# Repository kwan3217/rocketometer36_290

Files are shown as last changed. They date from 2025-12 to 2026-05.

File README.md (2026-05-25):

Moved to [GitHub](https://gitlab.com/kwan32171/rocketometer36_290)

This documents the data produced by the Rocketometer during NASA Sounding Rocket Flight 36.290, 2013 Oct 21.

# Encoding format
The data was captured and encoded in the form of CCSDS packets. The exact structure of each packet is most completely documented in the source code.

# Source code
The Rocketometer contains an LPC2148 ARM-based MCU with 512kiB flash memory. As this was far more memory than I needed for the firmware, I worked out a way to attach the source code of the firmware as well as the hardware design to the firmware itself. The Rocketometer spits this out into the packet stream as one of the first things it does at startup. How's that for configuration control?

The source code package is in the form of a ZPAQ TAR archive. The folder includes all the C++ source code, Makefiles, and such for rebuilding the firmware, which will be identical to the firmware carried on the flight with the exception of the date stamp on the firmware.

The hardware design is in the form of an Eagle CAD board and schematic, editable with the Eagle freeware version (as that is what it was designed with). It also includes a bill of materials in the form of Digikey catalog numbers for all parts used on the board.

The source code package is attached to the firmware, along with pointers to exactly where in the firmware the package begins and ends. This enables the firmware to copy a piece of itself into the packet stream as multiple CCSDS packets.

# Time Stamp
The firmware uses one of the MCU counter/timers for timing. This counter is a 32-bit unsigned number which starts at zero during firmware bootup, and counts up to one less than 3.6 billion counts exactly, at which point it resets to zero. The counter nominally runs at 60MHz, so this counter resets once every 60 seconds. Each time-sensitive packet (almost all of them except for some startup packets) have this count in it, and the packets are generated at such a rate that it is possible to unambiguously unwind the counter and get an exact number of counts since startup. Unfortunately the time of startup was not marked in any absolute time scale such as UTC, so absolute timing has to be inferred from timestamped events in the data.

# Sensor data
The sensor data stream consists of three separate streams of packets:
1. The Fast packet includes the MPU6050 3-axis acceleration, 3-axis rotation, and temperature readings, along with the ADXL377 3-axis high-acceleration readings. These were read once every 3 milliseconds and timestamped as indicated above.
2. The Compass packet includes the HMC5883 3-axis magnetic readouts. These were measured at a multiple of the Fast packet period (see the source code for details)
3. The BMP packet includes the BMP180 pressure and temperature readouts, both raw and calibrated into physical units.
4. The Power packet stream includes one packet each time the external power state changed (including one at startup).
5. The Vertical packet stream includes data on the vertical sensing fast/slow packet rate (see the source code for details). I have verified that this worked as intended, and that the entire flight was recorded at the fast rate.

# Packet storage
Packet storage was on a 16GB microSD card. Less than 1GB was used between the time I delivered the Rocketometer and the time it was returned to me.

# Power
The board consumes something around 100mA, not counting charging. The charger can use and additional 100mA. The system has an internal battery in the form of a 100mAh LiPo cell. The Rocketometer is powered externally by a 5V line from the rocket payload. It charges the battery with its on-board LiPo charging circuit as necessary when external power is available, and runs off the battery when external power is off. The on-board switch is not accessible, so the board is on whenever the rest of the rocket payload is on, and only turns off once its battery discharges. The battery is made safe by its standard integrated safety circuit and the dedicated LiPo charging circuit.

# The Flight
The Rocketometer was integrated with the rest of the rocket payload months before the flight. After that time, no human interaction whatsoever took place. It was returned to me for readout a couple of hours after the flight was completed. In that time, it recorded 65 files, one for each time it was power-cycled. The one containing the flight was file RKTO0620.SDS . This file contains 54.4 MB of data covering well over an hour, from about 35 minutes before the flight until well after impact. External power was cut 585 seconds after launch, and the on-board battery sustained it for the rest of the flight.

# Rail data
The file RKTO0620.SDS starts after the rail was raised to almost vertical. Other records were taken when the rail was horizontal, in particular RKTO0600.SDS. This data has been processed into the same tables and published. Interesting things such as orientation of the Rocketometer relative to the rail can be determined from that.

It would have been nice for the Rocketometer to have been recording while the rail was raised from horizontal to vertical. Unfortunately this did not happen. Maybe next time...

For whatever reason, it seems that no magnetic data was recorded while the rail was horizontal. Apparently magnetic data is not recorded when the board is recording at low rate.

# Rocketometer coordinate system
All sensors were co-aligned, so each individual sensor matches the whole Rocketometer frame. The Rocketometer was mounted close to the spin axis of the rocket, with the +Z axis pointed towards the tail. Consequently the thrust acceleration was primarily read out as a -Z acceleration. It should be parallel to that axis to within normal mechanical tolerances, almost certainly quite a bit better than 1°.

Based on the rail data, the +X axis of the Rocketometer was pointed almost straight down when the rocket was hanging horizontally from the rail.

In the flight after burnout but before spindown, the rocket was coasting well above the atmosphere and spinning with constant angular momentum, nearly around its long axis. Therefore the entire sensed acceleration is pure centripetal. Therefore, the distance and direction from the accelerometer to the spin axis can be measured. I did this once, but I wasn't sure about the signs and therefore didn't record it.

# Processing into tables
The packet stream format is not convenient or quick for import into IDL. For this purpose, a packet dumper, extractFast, was written in pure C which reads a Rocketometer data file, parses out each kind of packet, and writes each different apid into a different file. All the fast packets are together, all the slow packets, all the compass, all the source code, etc are each in their own file. Since the most common case is that each apid has a consistent length, this apid file can be read quickly into IDL by a read_binary, treating it as a 2D array of 16-bit integers, where rows are individual packets, and columns are fields in the packet.

Each packet is assigned a global sequence number, and this number is one of the things written to the APID file. With this sequence number, the order of different packets in different files can be determined.

These APID files are then imported into IDL, where the timestamps are normalized, values are converted in endian-ness as needed, and in general the packets are parsed. As this is an array operation, it can be done several orders of magnitude faster than parsing each packet individually in IDL.

The published tables have the timestamp normalized (cycle ambiguity fixed, converted into seconds, offset from power-on to launch subtracted) but otherwise the data is as recorded by the Rocketometer in flight. In particular, no translation from raw DNs to physical units is performed.

# Included files
* `RKTO0620.SDS.zip` - raw flight data file, PKZIP compressed
* `RKTO0600.SDS.zip` - raw rail data file, PKZIP compressed
* `firmware.tar.gz` - Firmware package, as flown (from RKTO0620.SDS) but zpaq uncompressed and gzip recompressed
* `extractFast.c` - C program described above
* `apid list.ods` - Some documentation of the packet format, not know to be completely up-to-date. Use the source code as the final authority.
* `import_fast.pro` - IDL program which converts extractFast output to CSV tables, among other things.
* `RKTO0620_csv.zip` - Compressed archive containing the following files
   * `RKTO0620_fast.csv` - Comma separated values, fast packets as described above
   * `RKTO0620_bmp.csv` - Comma separated values, BMP180 temperature and pressure readings, raw and calibrated into physical units by the Rocketometer in-flight
   * `RKTO0620_hmc.csv` - Comma separated values, HMC5883 magnetic readings, as described above.
* `RKTO0600_csv.zip` - Compressed archive containing the following files
   * `RKTO0600_fast.csv` - Comma separated values, fast packets as described above
   * `RKTO0600_bmp.csv` - Comma separated values, BMP180 temperature and pressure readings, raw and calibrated into physical units by the Rocketometer on-board

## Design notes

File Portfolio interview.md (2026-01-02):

1. Origin story -- What sparked this project 12+ years ago? Were you frustrated with 
  off-the-shelf loggers? Did a sounding rocket team need something better? Personal
  challenge?

The rollercoasterometer was inspired by Space Mountain. Most other roller coasters are
able to be seen. Space Mountain is unique for being in the dark. I wanted something to
trace the tracks. Other roller coasters could in principle use GPS, but Space Mountain,
being indoors, can't. I designed and implemented a fiber optic strain gauge accelerometer
for my senior project (2000-2001), thinking that something like that could be smuggled on
board in a back pack. This was about the time that MEMS sensors were becoming available, 
but they were out of reach for my budget. Fast forward several years to 2009. At this 
point, MEMS sensors were in their "Moore's Law" phase -- smaller, cheaper, more accurate, 
more axes, etc etc etc. I designed a breadboard-based "rollercoasterometer" which used several
Sparkfun breakout boards for several IMU and magnetic sensors plus a GPS, combined with a 
Sparkfun Logomatic with custom firmware. At the time I was working with SDO/EVE which includes
a sounding rocket component (documented in another page of the portfolio) and brought the
rollercoasterometer with me during various business trips, including one to the Cape for the
final Comprehensive Performance Test. The PI for SDO/EVE, Tom Woods, saw it, was impressed, 
and suggested that I put it on his sounding rocket. During the Cape trip I took it to Disney
World during a down day and successfully measured several roller coasters. However, in its
form, it was too large and heavy to fly.

While programming the Logomatic, I discovered that it was a quite powerful microcontroller
in its own right. Many people learned microcontrollers from Arduino. I got, used, and learned
from Arduino as well, but my first processor was the Logomatic and its controller, the LPC2148.
I learned about all of its additional features that the standard firmware didn't use. The stock
firmware is only capable of recording either ADC measurements or UART text streams, but not
both. I needed both since my IMUs were analog and the UART was connected to the GPS.

So, the Rocketometer is the natural evolution of the Rollercoasterometer. It is 0.9x2.1", less than
an ounce with 100mAh battery, and contains the next generation (2011-2012) digital IMU sensors. The 
Rocketometer doesn't have a GPS because stock civilian GPS units aren't designed for the 
dynamics a model rocket (or sounding rocket) experiences, and furthermore the sounding rocket mission
was inside an aluminum shell with controlled RF emission. They wouldn't have let me fly a GPS,
and it wouldn't have worked. Even so, the Rocketometer has a UART and can receive GPS and PPS
data and record it. It works fine as a rollercoasterometer.

Note that nowadays most smartphones contain sensors as good as those in the rocketometer, and I use
them along with a custom app to do my "rollercoasterometry" these days. I turn on the app, put the
phone in my pocket, and record the ride. This just didn't exist yet in 2009-2013.

2. The big technical constraints you had to wrestle -- Size, weight, power budget? 
   Vibration/shock levels you designed for? Sampling rate goals vs. what was actually 
   achievable? Any “this will never work” moments you solved?

The biggest technical constraint is that the rocketometer had no telemetry and no control
from the time I handed it to Dr Woods for integration into the sounding rocket. It had to
work completely unattended for months. This drove some design decisions:

* Power -- The rocketometer receives power from the rest of the payload, in the form of a +5VDC
  line. But, the payload is explicitly powered down before sounding rocket reentry, meaining
  that I needed to supply my own power for at least 10 minutes. The rocketometer used its charging
  circuit to top up its 100mAh battery from the provided 5V, then seamlessly uses the rail and battery
  during a mission. Once supplied power drops, the device seamlessly transitions to using the battery
  which provided 30 additional minutes of recording time, plenty enough for reentry.
* Data volume -- At the time, 16GB microSD cards were the state of the art. Furthermore, the card
  and filesystem driver in the firmware used FAT32, limiting files to just under 4GiB. To handle this, 
  the data stream was broken into 2GiB chunks. Each power cycle of the device started a new series
  of recording files, and each file was a 2GiB chunk of packet data. I wasn't sure how long the device
  would be powered up before, during, or after the launch campaign, so I designed a low-rate mode
  where it only sampled 1/10 as fast. The device would check whether it was vertical by watching its
  own IMU reaction to gravity. Whenever it measured vertical, it automatically shifted to high rate
  for the next 30min. It checked verticality every second, so the 30min timer started when the 
  sounding rocket burned out. I had paid attention to the Genesis spacecraft which had a flaw in its
  IMUs, which were installed backwards, and as a consequence didn't pop its parachute. So I programmed
  the rocketometer to declare vertical if the rocket was either nose-up or nose-down. It was a good thing
  since it was installed inverted from how I thought and vertical was being read as nose down. The
  raw data didn't depend on this, and the verticality detector worked, so the part recorded the flight
  just fine
* Software reliability -- I ran the part for days, accumulating runtime. If the part ever crashed,
  I used the debugging tools I could to find the issue and fix it. As it turns out, there were no
  crashes.

3. Key design decisions you’re still proud of -- Why bare-metal instead of an RTOS? Specific IMU 
   choice and why? Power sequencing tricks? Mechanical mounting/isolation? Anything you did that
   was unusually clever for the era?
Bare metal was a design decision I inherited from the Logomatic. The Rocketometer was in a sense a
re-spin of the open-source Sparkfun Logomatic. I took its design, added the sensors based on the 
reference design in each sensor's datasheet, and integrated the whole thing on a much smaller board.
The firmware eventually contained not one byte of Sparkfun code (I even rewrote the linker script 
and Makefiles) but that was more ship-of-Theseus. Bare metal is still the right way to go on this
part, and I leveraged my experience with AIM/CIPS flight software for a realtime bare-metal executive.

The thing that would count as "unusually clever" was my firmware's documentation of itself. Long
ago I put a feature into the rollercoasterometer which could dump the microcontroller's flash memory.
My thought was that this way I can see the machine code and debug it that way. But I realized that
there is a better way. I added a feature to the Makefile to make an archive of the entire source code
and hardware design files, then attach the archive to the binary firmware. The linker script put the
archive into a section and pointed some symbols at it, and the firmware at runtime interpreted those
symbols as pointers and dumped the firmware archive as packets. This way each packet stream contains
the source code of the device that generated it.

4. The sounding rocket flight -- Which program/vehicle was it (NASA Sounding Rocket, university, 
commercial)? What was your role on the payload team? Apogee of 285.1424 km is insane — was that a
record or near-record for that vehicle class? Any tense moments during integration or launch?

The rocket was `NASA 36.290 UE WOODS/UNIV. OF COLORADO` . This is a Terrier-Black Brant IX, two stage
sounding rocket. We launched from White Sands launch complex 36 on 2013-10-21. I assisted with ground
integration -- there are always more hands needed and not enough time in a sounding rocket launch. I
learned our telemetry system and made sure the realtime display worked, and then on launch day I was
the space weather observer. We didn't want to launch during a solar flare, so I watched our in-space
SDO/EVE realtime data and made the call and hour, 30 min, and 1 min before launch that no solar flares
were in progress.

The flight was completely smooth, being the sixth that this team had conducted. The tensest moment
for the rocketometer was when I got it back, took the MicroSD card out of it, put it in my laptop, and
the laptop said "What card?" It took a few minuted before it recognized the card, but once it did,
I had 419MiB of data, including 54.4MiB of data from the flight (and 64 other power cycles). I was able
to verify the launch acceleration pulse and then knew I had good data.

5. Data highlights -- What’s the coolest thing the data revealed? Cleanest plot you ever pulled off 
the SD card? Did it catch something the principal experiment missed? Any post-flight “holy crap, 
look at that spike” moments?

The data showed a 12G first stage, -1.5G between stages, about 8G second stage, and spikes of up to
25G during reentry. That was the most surprising thing -- zero G at 2100m/s, through a 25G spike, 
down to 1G terminal velocity in under 25 seconds. The upper atmosphere is a wall -- that's what 
exponential decay (or growth coming back down) does for you. It surprises a lot of people that 
reentry is so harsh. The scientists and engineers knew about the reentry and designed for it, but 
it's still surprising that reentry is more "violent" than launch. The sensor I launched had a range
of +-16G, which I knew was close to what was expected during launch. I included a secondary +-250G 
sensor to catch data where the primary sensor saturated.

Also, the pressure sensor was rated from 0.3 to 1.3 bar, but did record 0 bar during the in-space
portion of the flight. It's just that the exact readings below 0.3 bar can't be trusted.

6. Failures or near-failures -- Be honest — any flights where it didn’t work perfectly? What broke,
and what did you change for the next one? SpaceX loves people who’ve debugged real hardware in the
field.

Alan Stern said about New Horizons at Pluto, that during the encounter, they don't want to learn
anything new about the spacecraft, only about Pluto. All of the bugs/"interesting features" are
to be known before encounter during rehearsals etc and fixed, worked around, or planned for.
I basically achieved that. The nose-down reading could have scuttled it, but the worst case
would have been recording the flight at 1/10 of design data rate, not "no data". By the time of the
sounding rocket, this exact device had flown in a model rocket, run for days on end, and was as
good as I could make it.

7. Longevity angle -- You said it’s 12 years old and still works — have you powered it up recently?
Flown it again? Still have the exact as-flown code running on the bench?

The flight was 12 years ago. The primary mission was for me to collect a piece of space-flown 
hardware as a "trophy". I still have it, mounted on a plaque for my mantel. It is only a trophy now.
I think that it still works, but the last time I fired it up was about 3 years ago, and I didn't
test the sensors, just the microcontroller.

8. Personal touches -- The embroidered patch — whose idea? Did you design it? Any other fun 
artifacts (stickers, T-shirts, war stories from the range)?

Every space mission needs a patch, and I designed one for this mission. It's pretty typical for
space mission patches. It has an oval shape with a picture of a 1950's sci-fi rocket with flames
coming out of it, connected to a voltmeter by two wires. The rocket represents the "rocket-" part
and the voltmeter represents the "-ometer" part. The rocket is high above the curved horizon of Earth.
In the background, there are 3 big and 2 small stars to the left of the rocket, and 1 big and
7 small stars to the right. This represents kwan3217. The border has the text "Rocketometer 36.290"
on the top of the oval, and "NASA - CU/LASP - SKHFTTADD" on the bottom where crew names (for manned flights)
or organization names (for unmanned flights) go. NASA and CU/LASP are obvious. SKHFTTADD is "St Kwan's Home
for the Terminally ADD", which is a pseudo-organization I made for myself.

I made several tab shirts with this patch embroidered into it, and also made some stickers which I stuck
on the tail fin of the first stage and on a window in the blockhouse next to stickers from all of their
other missions.

9. SpaceX hook -- When you imagine a Starship flight test engineer looking at this page, what do
you most want them to think? What part of Rocketometer feels closest to the instrumentation
challenges on Starship or Raptor test stands?

The biggest application to SpaceX is that I am a competent hardware and software designer, able
to integrate parts with "glue logic" like the custom PCB and microcontroller firmware, and that
I incorporate the NASA philosophy that I learned from the projects at LASP and conducted an 
experiment/built an instrument/implemented a project from beginning to end.

10. One-sentence elevator pitch -- If you had 10 seconds with Elon or a Starship avionics lead, how would you describe Rocketometer in one breath?

Custom microcontroller board with integrated IMU, battle-tested in space flight.

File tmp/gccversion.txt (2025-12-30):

Using built-in specs.
COLLECT_GCC=arm-none-eabi-gcc
COLLECT_LTO_WRAPPER=/usr/local/arm/libexec/gcc/arm-none-eabi/4.7.2/lto-wrapper
arm-none-eabi-gcc (GCC) 4.7.2
Copyright (C) 2012 Free Software Foundation, Inc.
This is free software; see the source for copying conditions.  There is NO
warranty; not even for MERCHANTABILITY or FITNESS FOR A PARTICULAR PURPOSE.

Target: arm-none-eabi
Configured with: ../gcc-4.7.2/configure --target=arm-none-eabi --prefix=/usr/local/arm --enable-interwork --enable-multilib --enable-languages=c,c++ --with-newlib --with-gnu-as --with-gnu-ld --disable-nls --disable-shared --disable-threads --with-headers=newlib/libc/include --disable-libssp --disable-libstdcxx-pch --disable-libmudflap --disable-libgomp --disable-werror --with-system-zlib --disable-newlib-supplied-syscalls
Thread model: single
gcc version 4.7.2 (GCC) 
COLLECT_GCC_OPTIONS='--version' '-v'
 /usr/local/arm/libexec/gcc/arm-none-eabi/4.7.2/cc1 -quiet -v -D__USES_INITFINI__ help-dummy -quiet -dumpbase help-dummy -auxbase help-dummy -version --version -o /tmp/ccWipwGV.s
GNU C (GCC) version 4.7.2 (arm-none-eabi)
	compiled by GNU C version 4.6.3, GMP version 4.3.2, MPFR version 2.4.2, MPC version 0.8.1
GGC heuristics: --param ggc-min-expand=100 --param ggc-min-heapsize=131072
COLLECT_GCC_OPTIONS='--version' '-v'
 /usr/local/arm/lib/gcc/arm-none-eabi/4.7.2/../../../../arm-none-eabi/bin/as -v -meabi=5 --version -o /tmp/ccyAZ0tG.o /tmp/ccWipwGV.s
GNU assembler version 2.22 (arm-none-eabi) using BFD version (GNU Binutils) 2.22
GNU assembler (GNU Binutils) 2.22
Copyright 2011 Free Software Foundation, Inc.
This program is free software; you may redistribute it under the terms of
the GNU General Public License version 3 or later.
This program has absolutely no warranty.
This assembler was configured for a target of `arm-none-eabi'.
COMPILER_PATH=/usr/local/arm/libexec/gcc/arm-none-eabi/4.7.2/:/usr/local/arm/libexec/gcc/arm-none-eabi/4.7.2/:/usr/local/arm/libexec/gcc/arm-none-eabi/:/usr/local/arm/lib/gcc/arm-none-eabi/4.7.2/:/usr/local/arm/lib/gcc/arm-none-eabi/:/usr/local/arm/lib/gcc/arm-none-eabi/4.7.2/../../../../arm-none-eabi/bin/
LIBRARY_PATH=/usr/local/arm/lib/gcc/arm-none-eabi/4.7.2/:/usr/local/arm/lib/gcc/arm-none-eabi/4.7.2/../../../../arm-none-eabi/lib/
COLLECT_GCC_OPTIONS='--version' '-v'
 /usr/local/arm/libexec/gcc/arm-none-eabi/4.7.2/collect2 -X --version /usr/local/arm/lib/gcc/arm-none-eabi/4.7.2/crti.o /usr/local/arm/lib/gcc/arm-none-eabi/4.7.2/crtbegin.o /usr/local/arm/lib/gcc/arm-none-eabi/4.7.2/../../../../arm-none-eabi/lib/crt0.o -L/usr/local/arm/lib/gcc/arm-none-eabi/4.7.2 -L/usr/local/arm/lib/gcc/arm-none-eabi/4.7.2/../../../../arm-none-eabi/lib /tmp/ccyAZ0tG.o --start-group -lgcc -lc --end-group /usr/local/arm/lib/gcc/arm-none-eabi/4.7.2/crtend.o /usr/local/arm/lib/gcc/arm-none-eabi/4.7.2/crtn.o
collect2 version 4.7.2
/usr/local/arm/lib/gcc/arm-none-eabi/4.7.2/../../../../arm-none-eabi/bin/ld -X --version /usr/local/arm/lib/gcc/arm-none-eabi/4.7.2/crti.o /usr/local/arm/lib/gcc/arm-none-eabi/4.7.2/crtbegin.o /usr/local/arm/lib/gcc/arm-none-eabi/4.7.2/../../../../arm-none-eabi/lib/crt0.o -L/usr/local/arm/lib/gcc/arm-none-eabi/4.7.2 -L/usr/local/arm/lib/gcc/arm-none-eabi/4.7.2/../../../../arm-none-eabi/lib /tmp/ccyAZ0tG.o --start-group -lgcc -lc --end-group /usr/local/arm/lib/gcc/arm-none-eabi/4.7.2/crtend.o /usr/local/arm/lib/gcc/arm-none-eabi/4.7.2/crtn.o
GNU ld (GNU Binutils) 2.22
Copyright 2011 Free Software Foundation, Inc.
This program is free software; you may redistribute it under the terms of
the GNU General Public License version 3 or (at your option) a later version.
This program has absolutely no warranty.

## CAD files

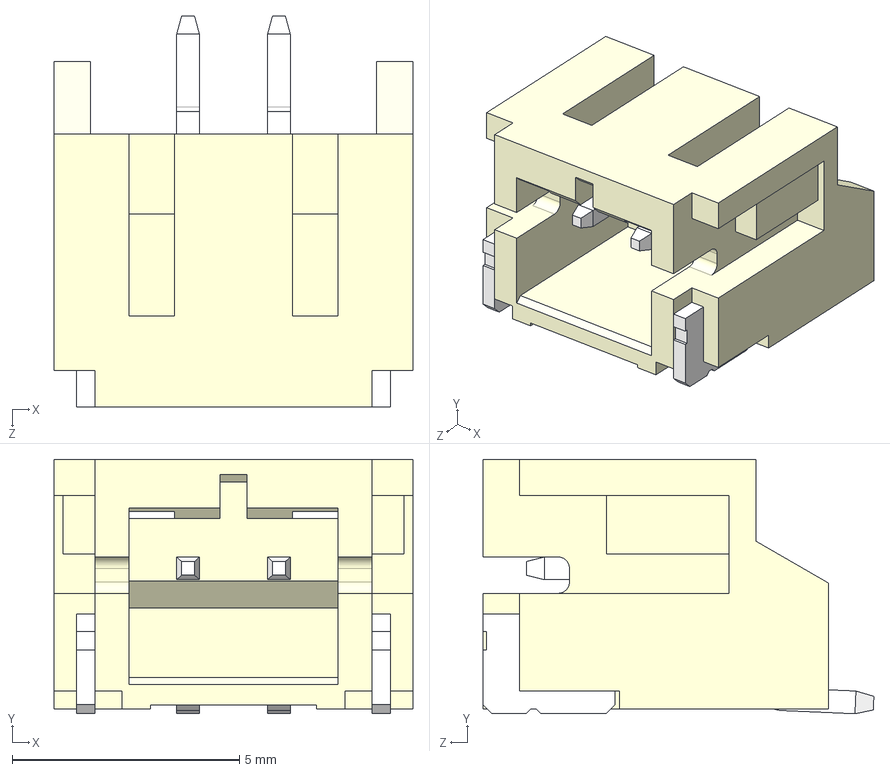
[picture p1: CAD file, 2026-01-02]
kicad/S2B-PH-SM4-TB.STEP
7.90 x 5.60 x 8.60 mm

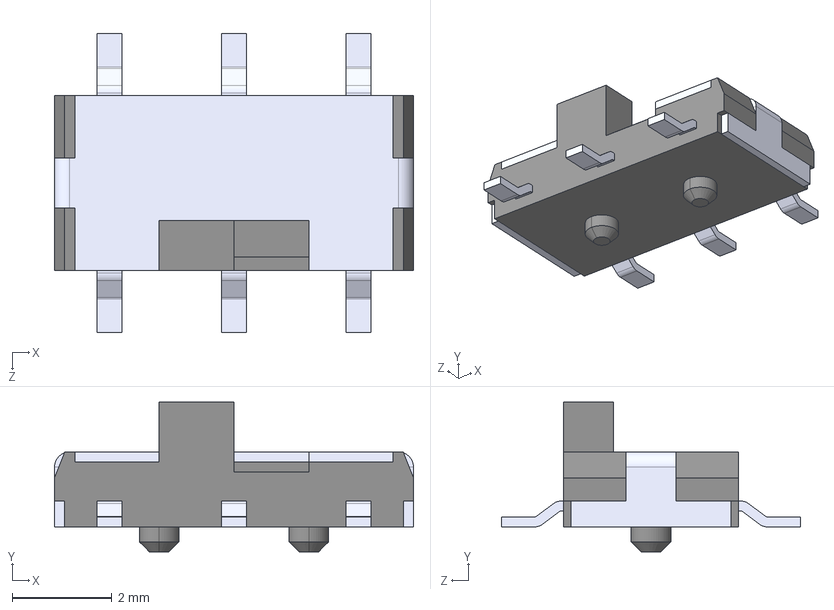
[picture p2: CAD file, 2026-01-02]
kicad/AYZ0202AGRLC.STEP
7.20 x 3.00 x 6.00 mm

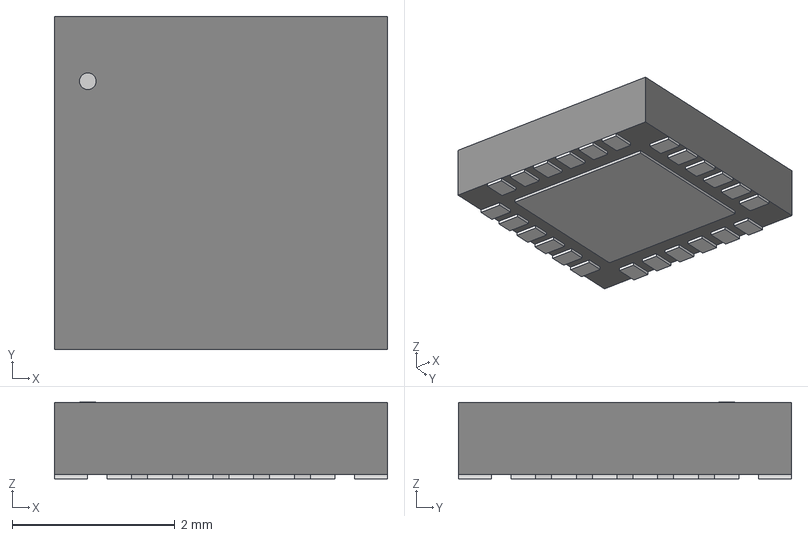
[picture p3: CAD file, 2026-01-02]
kicad/QFN24_4X4X0P9-0P5_TDK.step
4.09 x 4.09 x 0.942 mm

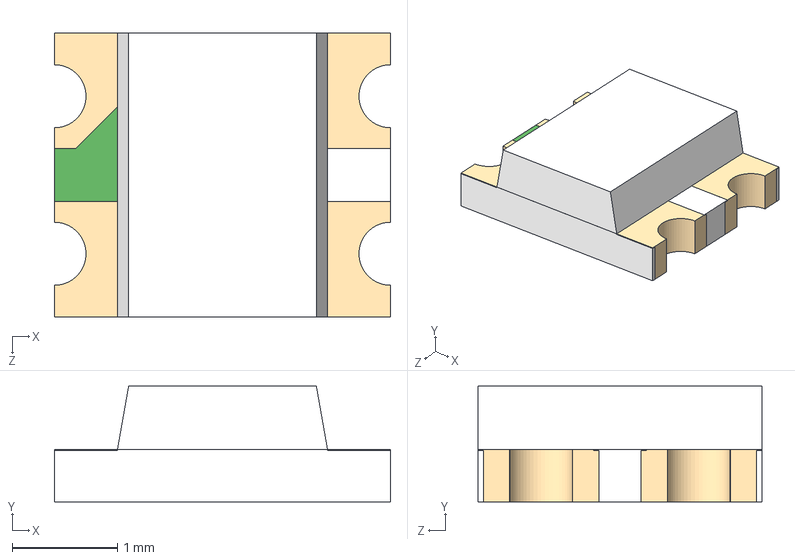
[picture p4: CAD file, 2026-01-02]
kicad/HSMF-C118.STEP
3.20 x 1.10 x 2.70 mm

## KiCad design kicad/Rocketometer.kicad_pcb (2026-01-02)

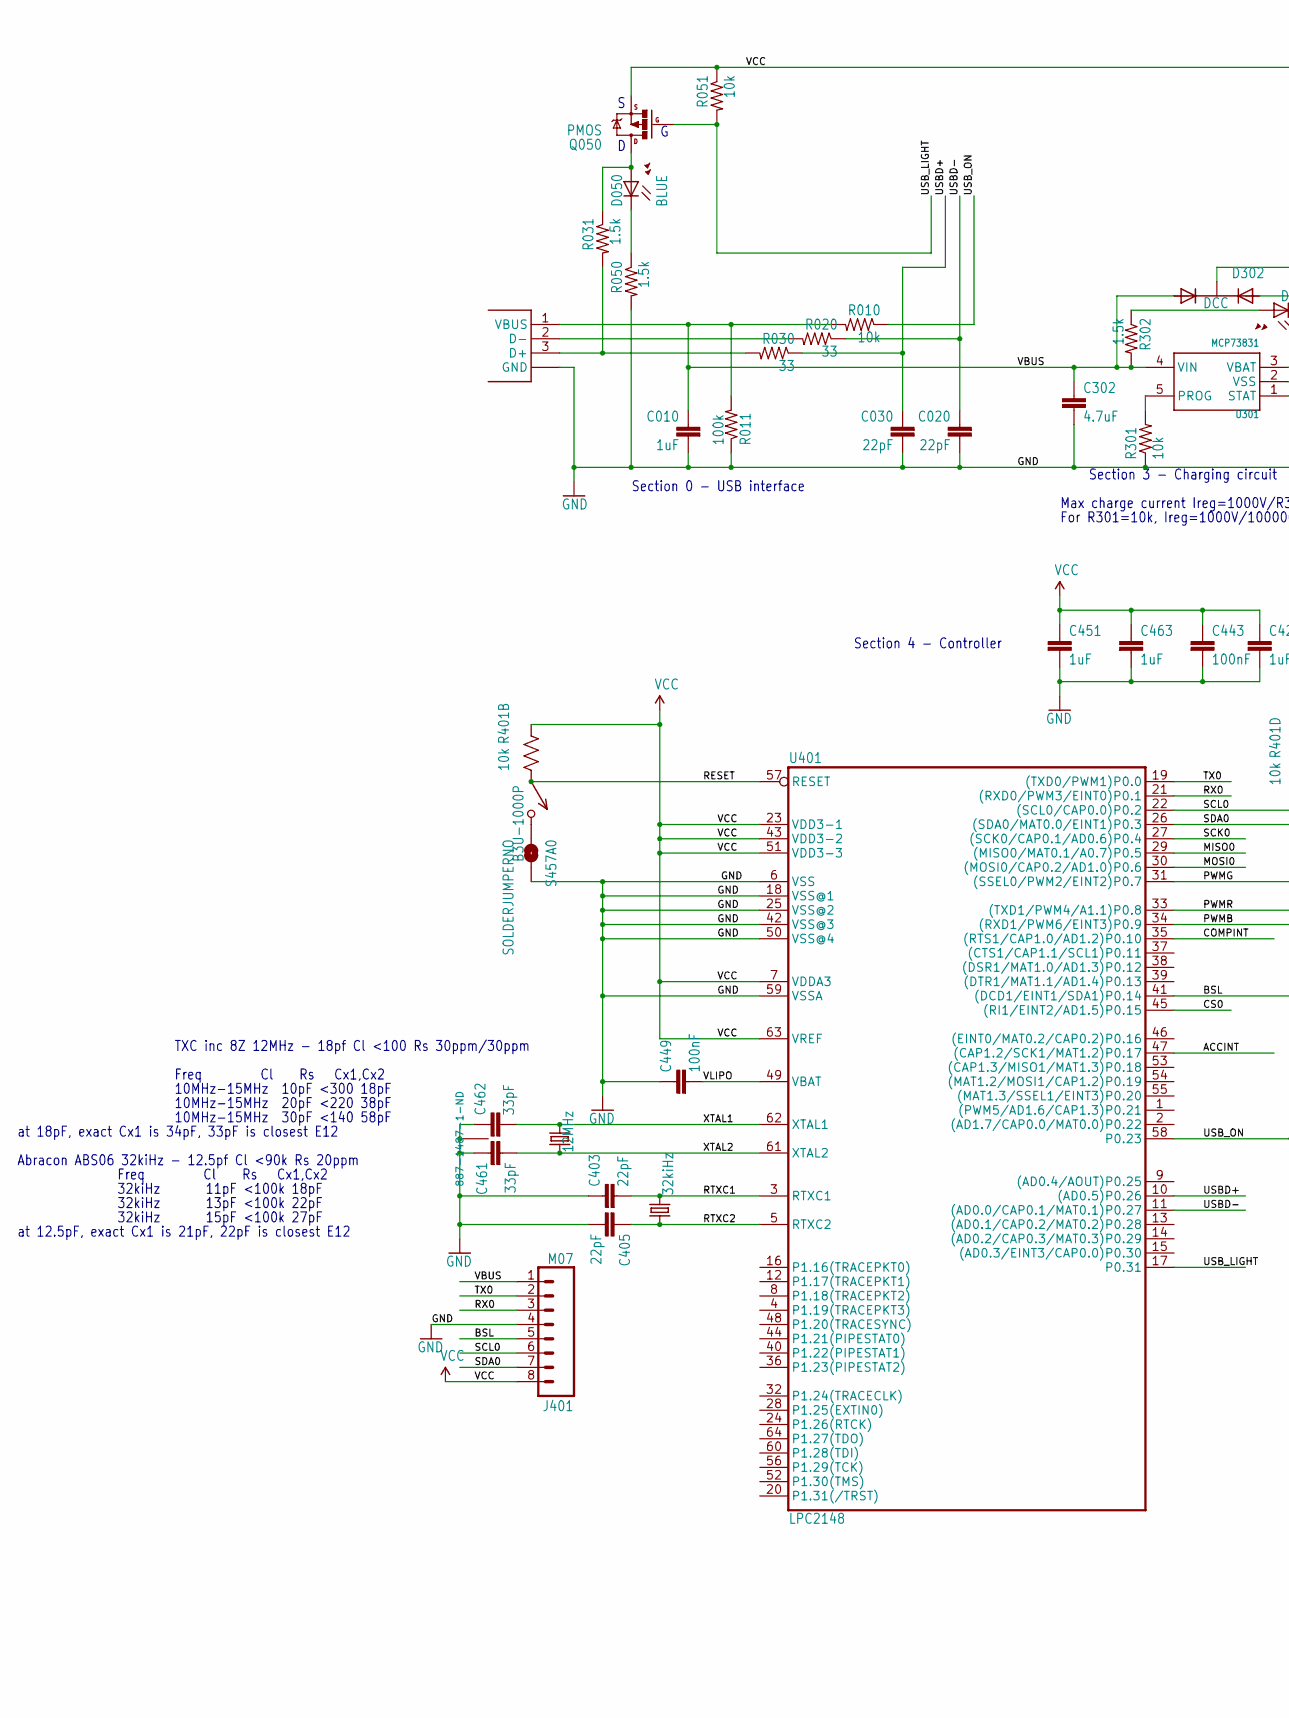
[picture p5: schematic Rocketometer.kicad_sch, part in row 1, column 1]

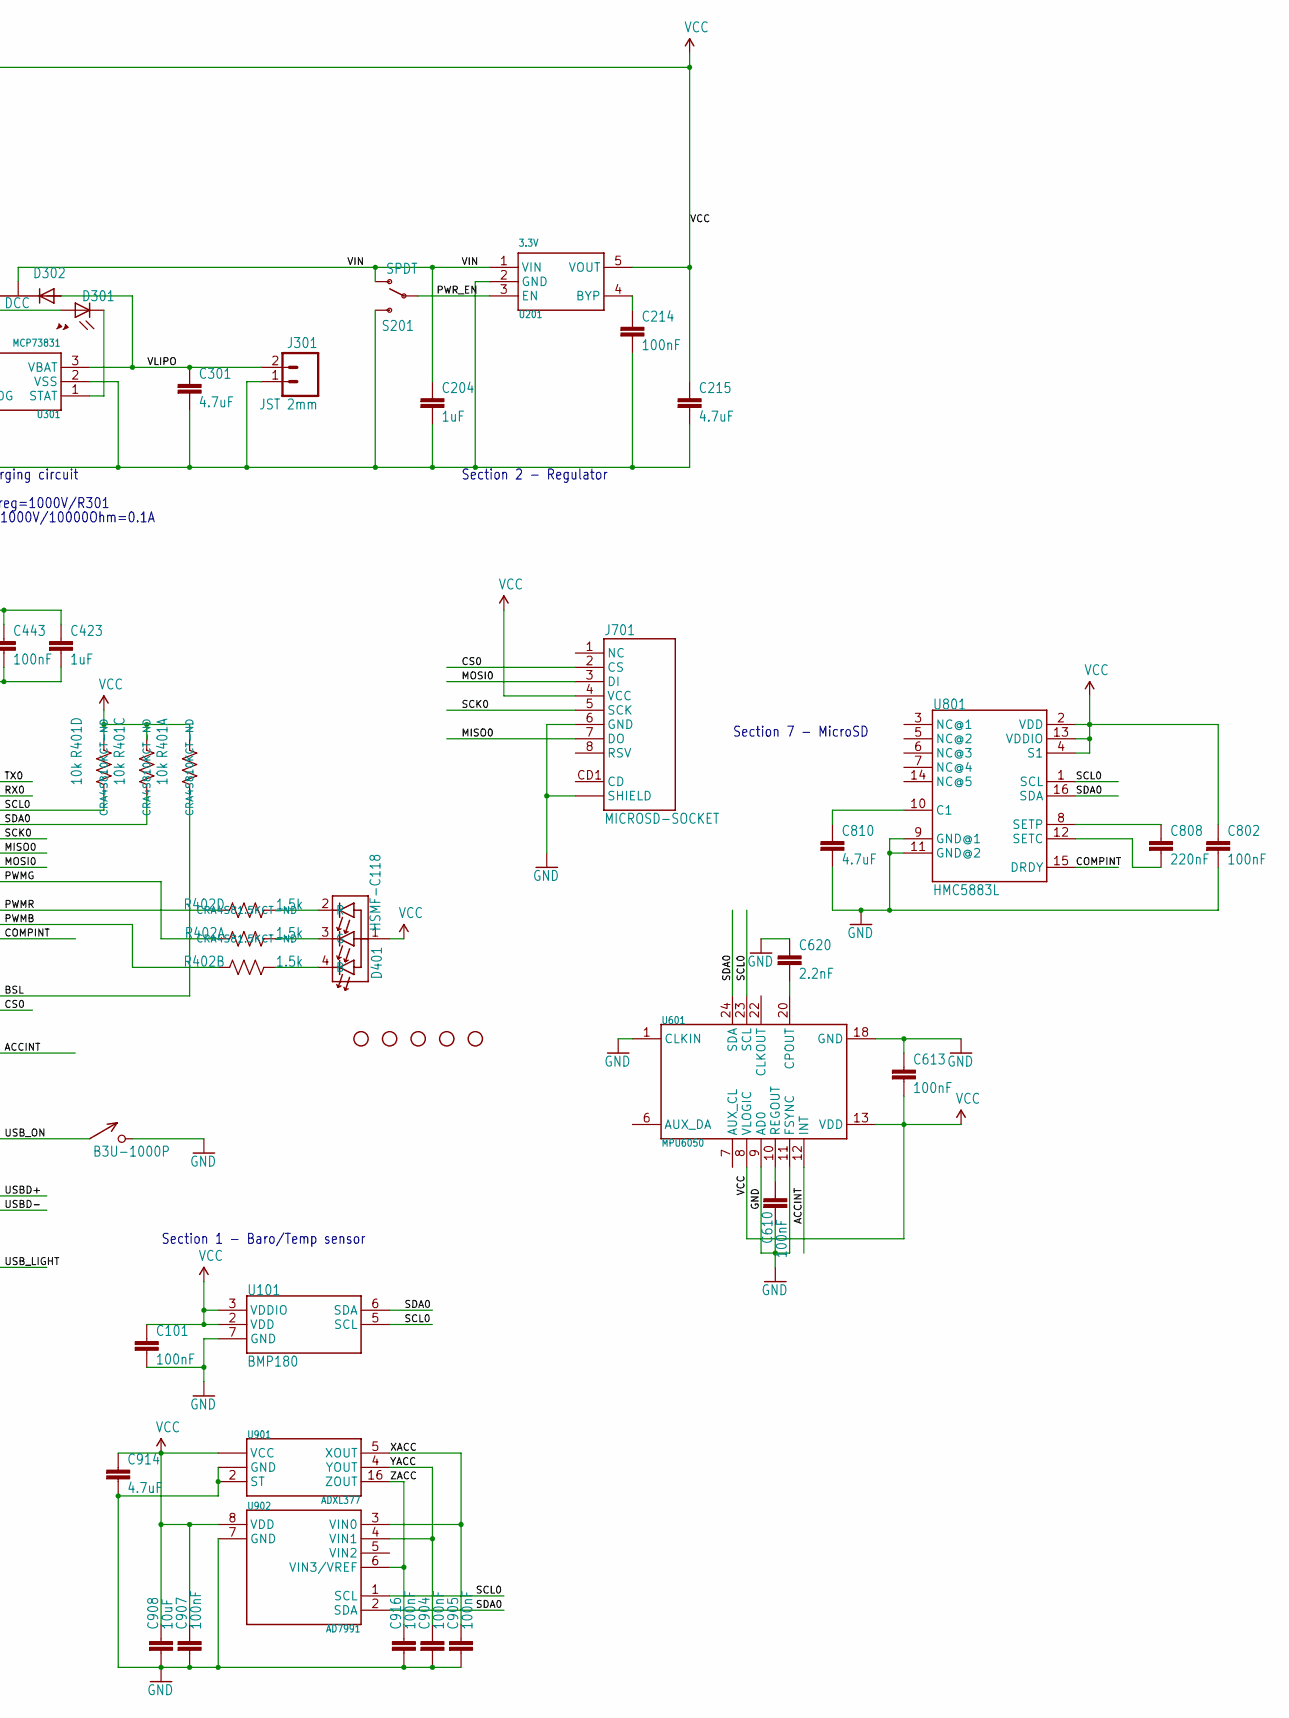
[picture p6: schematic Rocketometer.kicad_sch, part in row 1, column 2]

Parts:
C010, C204, C423, C451, C463: 1uF; 0402-CAP; DIGIKEY 445-4114-1-ND
C020, C030, C403, C405: 22pF; 0402-CAP; DIGIKEY 445-1239-1-ND
C101, C214, C443, C449, C610, C613, C802, C904, C905, C907, C916: 100nF; 0402-CAP; DIGIKEY 445-1265-1-ND
C215, C301, C302, C810, C914: 4.7uF; 0402-CAP; DIGIKEY 445-7395-1-ND
C461, C462: 33pF; 0402-CAP; DIGIKEY 445-1241-1-ND
C620: 2.2nF; 0402-CAP; DIGIKEY 445-1257-1-ND
C808: 220nF; 0402-CAP; DIGIKEY 445-5938-1-ND
C908: 10uF; 0603-CAP; DIGIKEY 445-7486-1-ND
D050: BLUE; LED-0603; DIGIKEY 350-2037-1-ND
D301: YELLOW; LED-0603; DIGIKEY 350-2032-1-ND
D302: DCC; SOT-23-3; DIGIKEY 568-6500-1-ND
D401: HSMF-C118; DIGIKEY 516-1778-1-ND
J001: USB_MICROB_JST; UB-MC5BR3-SD204-4S; DIGIKEY 455-2562-1-ND
J301: JST 2mm; JST-2-SMD; DIGIKEY 455-1749-1-ND
J401: M07; 1X08; DIGIKEY $NOPART
J701: MICROSD-SOCKET; MICROSD-SOCKET-PP; DIGIKEY 101-00581-59-1-ND
JP1, JP2, JP3, JP4, JP5: STAND-OFFTIGHT; STAND-OFF-TIGHT; DIGIKEY $NOPART
Q050: PMOS; SOT23-3; DIGIKEY NTR1P02T1GOSCT-ND
R010, R051, R301: 10k; 0402-RES; DIGIKEY P10.0KLCT-ND
R011: 100k; 0402-RES; DIGIKEY P100KLCT-ND
R020, R030: 33; 0402-RES; DIGIKEY P33.0LCT-ND
R031, R050, R302: 1.5k; 0402-RES; DIGIKEY P1.50KLCT-ND
R401: 10k; CRA04; DIGIKEY CRA4S810KCT-ND
R402: 1.5k; CRA04; DIGIKEY CRA4S81.5KCT-ND
S201: SPDT; AYZ0202; DIGIKEY 401-2013-1-ND
S457, S458: B3U-1000P; DIGIKEY SW1020CT-ND
S457A0: SOLDERJUMPERNO; SJ_2S-NO; DIGIKEY $NOPART
U101: BMP180; DIGIKEY 828-1027-1-ND
U201: 3.3V; SOT-23-5; DIGIKEY 576-1910-1-ND
U301: MCP73831; SOT-23-5; DIGIKEY 576-1910-1-ND
U401: LPC2148; SQFP-S-10X10-64; DIGIKEY 568-1765-ND
U601: MPU6050; MPU60X0; DIGIKEY $NOPART
U801: HMC5883L; 16LPCC; DIGIKEY 342-1082-1-ND
U901: ADXL377; DIGIKEY ADXL377BCPZ-RL7CT-ND
U902: AD7991; SOT-23-8; DIGIKEY AD7991YRJZ-0500RL7CT-ND
Y401: 12MHz; CRYSTAL_SMD_2MM_2_5MM; DIGIKEY 887-1487-1-ND
Y402: 32kiHz; ABS06; DIGIKEY 535-10104-1-ND

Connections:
ACCINT: U401.47 ((CAP1.2/SCK1/MAT1.2)P0.17), U601.12 (INT)
BSL: J401.5, R401.1, U401.41 ((DCD1/EINT1/SDA1)P0.14)
COMPINT: U401.35 ((RTS1/CAP1.0/AD1.2)P0.10), U801.15 (DRDY)
CONN_D+: J001.3 (D+), R030.2, R031.2
CONN_D-: J001.2 (D-), R020.2
CS0: J701.2 (CS), U401.45 ((RI1/EINT2/AD1.5)P0.15)
GND: C010.2, C020.2, C030.2, C101.2, C204.2, C214.2, C215.2, C301.2, C302.2, C403.1, C405.2, C423.2, C443.2, C449.1, C451.2, C461.1, C462.1, C463.2, C610.2, C613.1, C620.1, C802.2, C810.2, C904.2, C905.2, C907.2, C908.2, C914.2, C916.2, J001.5 (GND), J001.P$6 (GND), J001.P$7 (GND), J001.P$8 (GND), J001.P$9 (GND), J001.P$10 (GND), J001.P$11 (GND), J301.1, J401.4, J701.6 (GND), J701.CD2 (SHIELD), J701.GND1 (SHIELD), J701.GND3 (SHIELD), R011.1, R050.2, R301.1, S201.3 (S), S457A0.2, S458.P$2 (2), U101.7 (GND), U201.2 (GND), U301.2 (VSS), U401.6 (VSS), U401.18 (VSS@1), U401.25 (VSS@2), U401.42 (VSS@3), U401.50 (VSS@4), U401.59 (VSSA), U601.1 (CLKIN), U601.9 (AD0), U601.11 (FSYNC), U601.18 (GND), U801.9 (GND@1), U801.11 (GND@2), U901.2 (ST), U901.6 (GND), U901.7 (GND), U902.7 (GND), Y401.2 (1), Y401.4 (1)
MISO0: J701.7 (DO), U401.29 ((MISO0/MAT0.1/A0.7)P0.5)
MOSI0: J701.3 (DI), U401.30 ((MOSI0/CAP0.2/AD1.0)P0.6)
unnamed: C620.2, U601.20 (CPOUT)
unnamed: R301.2, U301.5 (PROG)
unnamed: D301.C, U301.1 (STAT)
unnamed: D301.A, R302.1
unnamed: D050.A, Q050.3 (D), R031.1
unnamed: D050.C, R050.1
unnamed: S457.P$2 (2), S457A0.1
unnamed: C610.1, U601.10 (REGOUT)
unnamed: C808.1, U801.8 (SETP)
unnamed: C808.2, U801.12 (SETC)
unnamed: C810.1, U801.10 (C1)
unnamed: C214.1, U201.4 (BYP)
PWMB: R402.7 (2), U401.34 ((RXD1/PWM6/EINT3)P0.9)
PWMG: R402.8 (2), U401.31 ((SSEL0/PWM2/EINT2)P0.7)
PWMR: R402.5 (2), U401.33 ((TXD1/PWM4/A1.1)P0.8)
PWR_EN: S201.2, U201.3 (EN)
QWMB: D401.4 (B), R402.2 (1)
QWMG: D401.3 (G), R402.1
QWMR: D401.2 (R), R402.4 (1)
RESET: R401.2 (1), S457.P$1 (1), U401.57 (RESET)
RTXC1: C403.2, U401.3 (RTXC1), Y402.2
RTXC2: C405.1, U401.5 (RTXC2), Y402.1
RX0: J401.3, U401.21 ((RXD0/PWM3/EINT0)P0.1)
SCK0: J701.5 (SCK), U401.27 ((SCK0/CAP0.1/AD0.6)P0.4)
SCL0: J401.6, R401.4 (1), U101.5 (SCL), U401.22 ((SCL0/CAP0.0)P0.2), U601.23 (SCL), U801.1 (SCL), U902.1 (SCL)
SDA0: J401.7, R401.3 (1), U101.6 (SDA), U401.26 ((SDA0/MAT0.0/EINT1)P0.3), U601.24 (SDA), U801.16 (SDA), U902.2 (SDA)
TX0: J401.2, U401.19 ((TXD0/PWM1)P0.0)
USBD+: C030.1, R030.1, U401.10 ((AD0.5)P0.26)
USBD-: C020.1, R020.1, U401.11 ((AD0.0/CAP0.1/MAT0.1)P0.27)
USB_LIGHT: Q050.1 (G), R051.2, U401.17 (P0.31)
USB_ON: R010.1, S458.P$1 (1), U401.58 (P0.23)
VBUS: C010.1, C302.1, D302.1 (A1), J001.1 (VBUS), J401.1, R010.2, R011.2, R302.2, U301.4 (VIN)
VCC: C101.1, C215.1, C423.1, C443.1, C451.1, C463.1, C613.2, C802.1, C907.1, C908.1, C914.1, D401.1 (A), J401.8, J701.4 (VCC), Q050.2 (S), R051.1, R401.5 (2), R401.6 (2), R401.7 (2), R401.8 (2), U101.2 (VDD), U101.3 (VDDIO), U201.5 (VOUT), U401.7 (VDDA3), U401.23 (VDD3-1), U401.43 (VDD3-2), U401.51 (VDD3-3), U401.63 (VREF), U601.8 (VLOGIC), U601.13 (VDD), U801.2 (VDD), U801.4 (S1), U801.13 (VDDIO), U901.14 (VCC), U901.15 (VCC), U902.8 (VDD)
VIN: C204.1, D302.3 (K), S201.1 (O), U201.1 (VIN)
VLIPO: C301.1, C449.2, D302.2 (A2), J301.2, U301.3 (VBAT), U401.49 (VBAT)
XACC: C905.1, U901.5 (XOUT), U902.3 (VIN0)
XTAL1: C462.2, U401.62 (XTAL1), Y401.3 (2)
XTAL2: C461.2, U401.61 (XTAL2), Y401.1
YACC: C904.1, U901.4 (YOUT), U902.4 (VIN1)
ZACC: C916.1, U901.16 (ZOUT), U902.6 (VIN3/VREF)

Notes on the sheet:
10MHz-15MHz 30pF <140 58pF
10MHz-15MHz 10pF <300 18pF
Section 4 - Controller
Section 7 - MicroSD
Section 2 - Regulator
10MHz-15MHz 20pF <220 38pF
32kiHz 13pF <100k 22pF
Section 0 - USB interface
For R301=10k, Ireg=1000V/10000Ohm=0.1A
32kiHz 11pF <100k 18pF
Section 1 - Baro/Temp sensor
32kiHz 15pF <100k 27pF
TXC inc 8Z 12MHz - 18pf Cl <100 Rs 30ppm/30ppm
Freq Cl Rs Cx1,Cx2
Section 3 - Charging circuit
Max charge current Ireg=1000V/R301
at 12.5pF, exact Cx1 is 21pF, 22pF is closest E12
at 18pF, exact Cx1 is 34pF, 33pF is closest E12
Abracon ABS06 32kiHz - 12.5pf Cl <90k Rs 20ppm

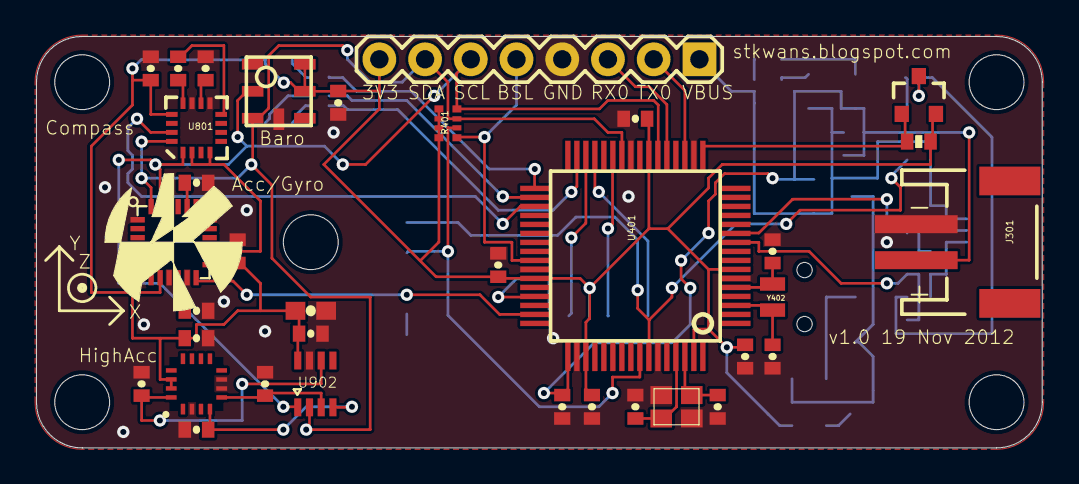
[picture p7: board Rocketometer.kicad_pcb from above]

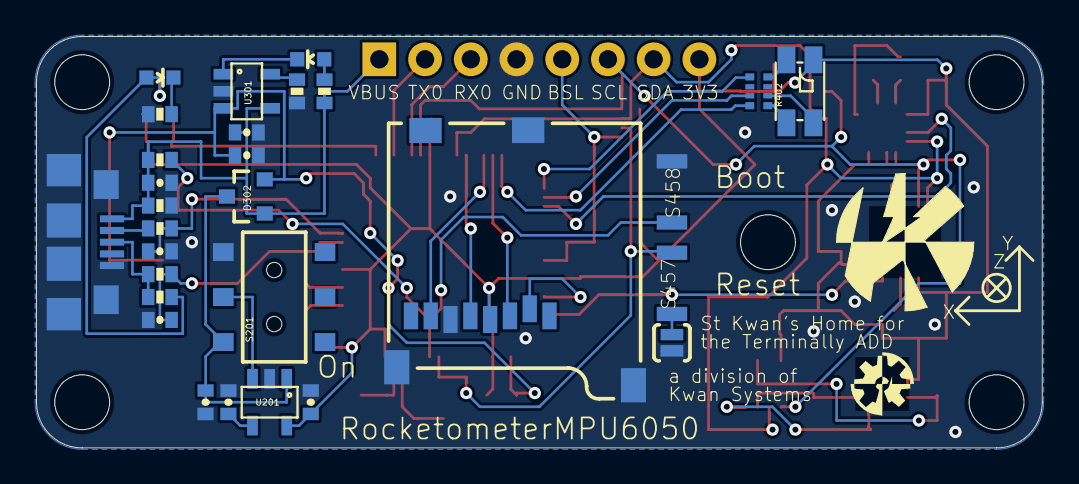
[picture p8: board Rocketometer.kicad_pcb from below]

Board: 2 copper layers, 55.9 x 22.9 mm, 73 parts (31 on the bottom side), 49 nets.

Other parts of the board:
U$1, U$5: KWAN_ACC
U$4: AXES
U$6: OSHW_ACC

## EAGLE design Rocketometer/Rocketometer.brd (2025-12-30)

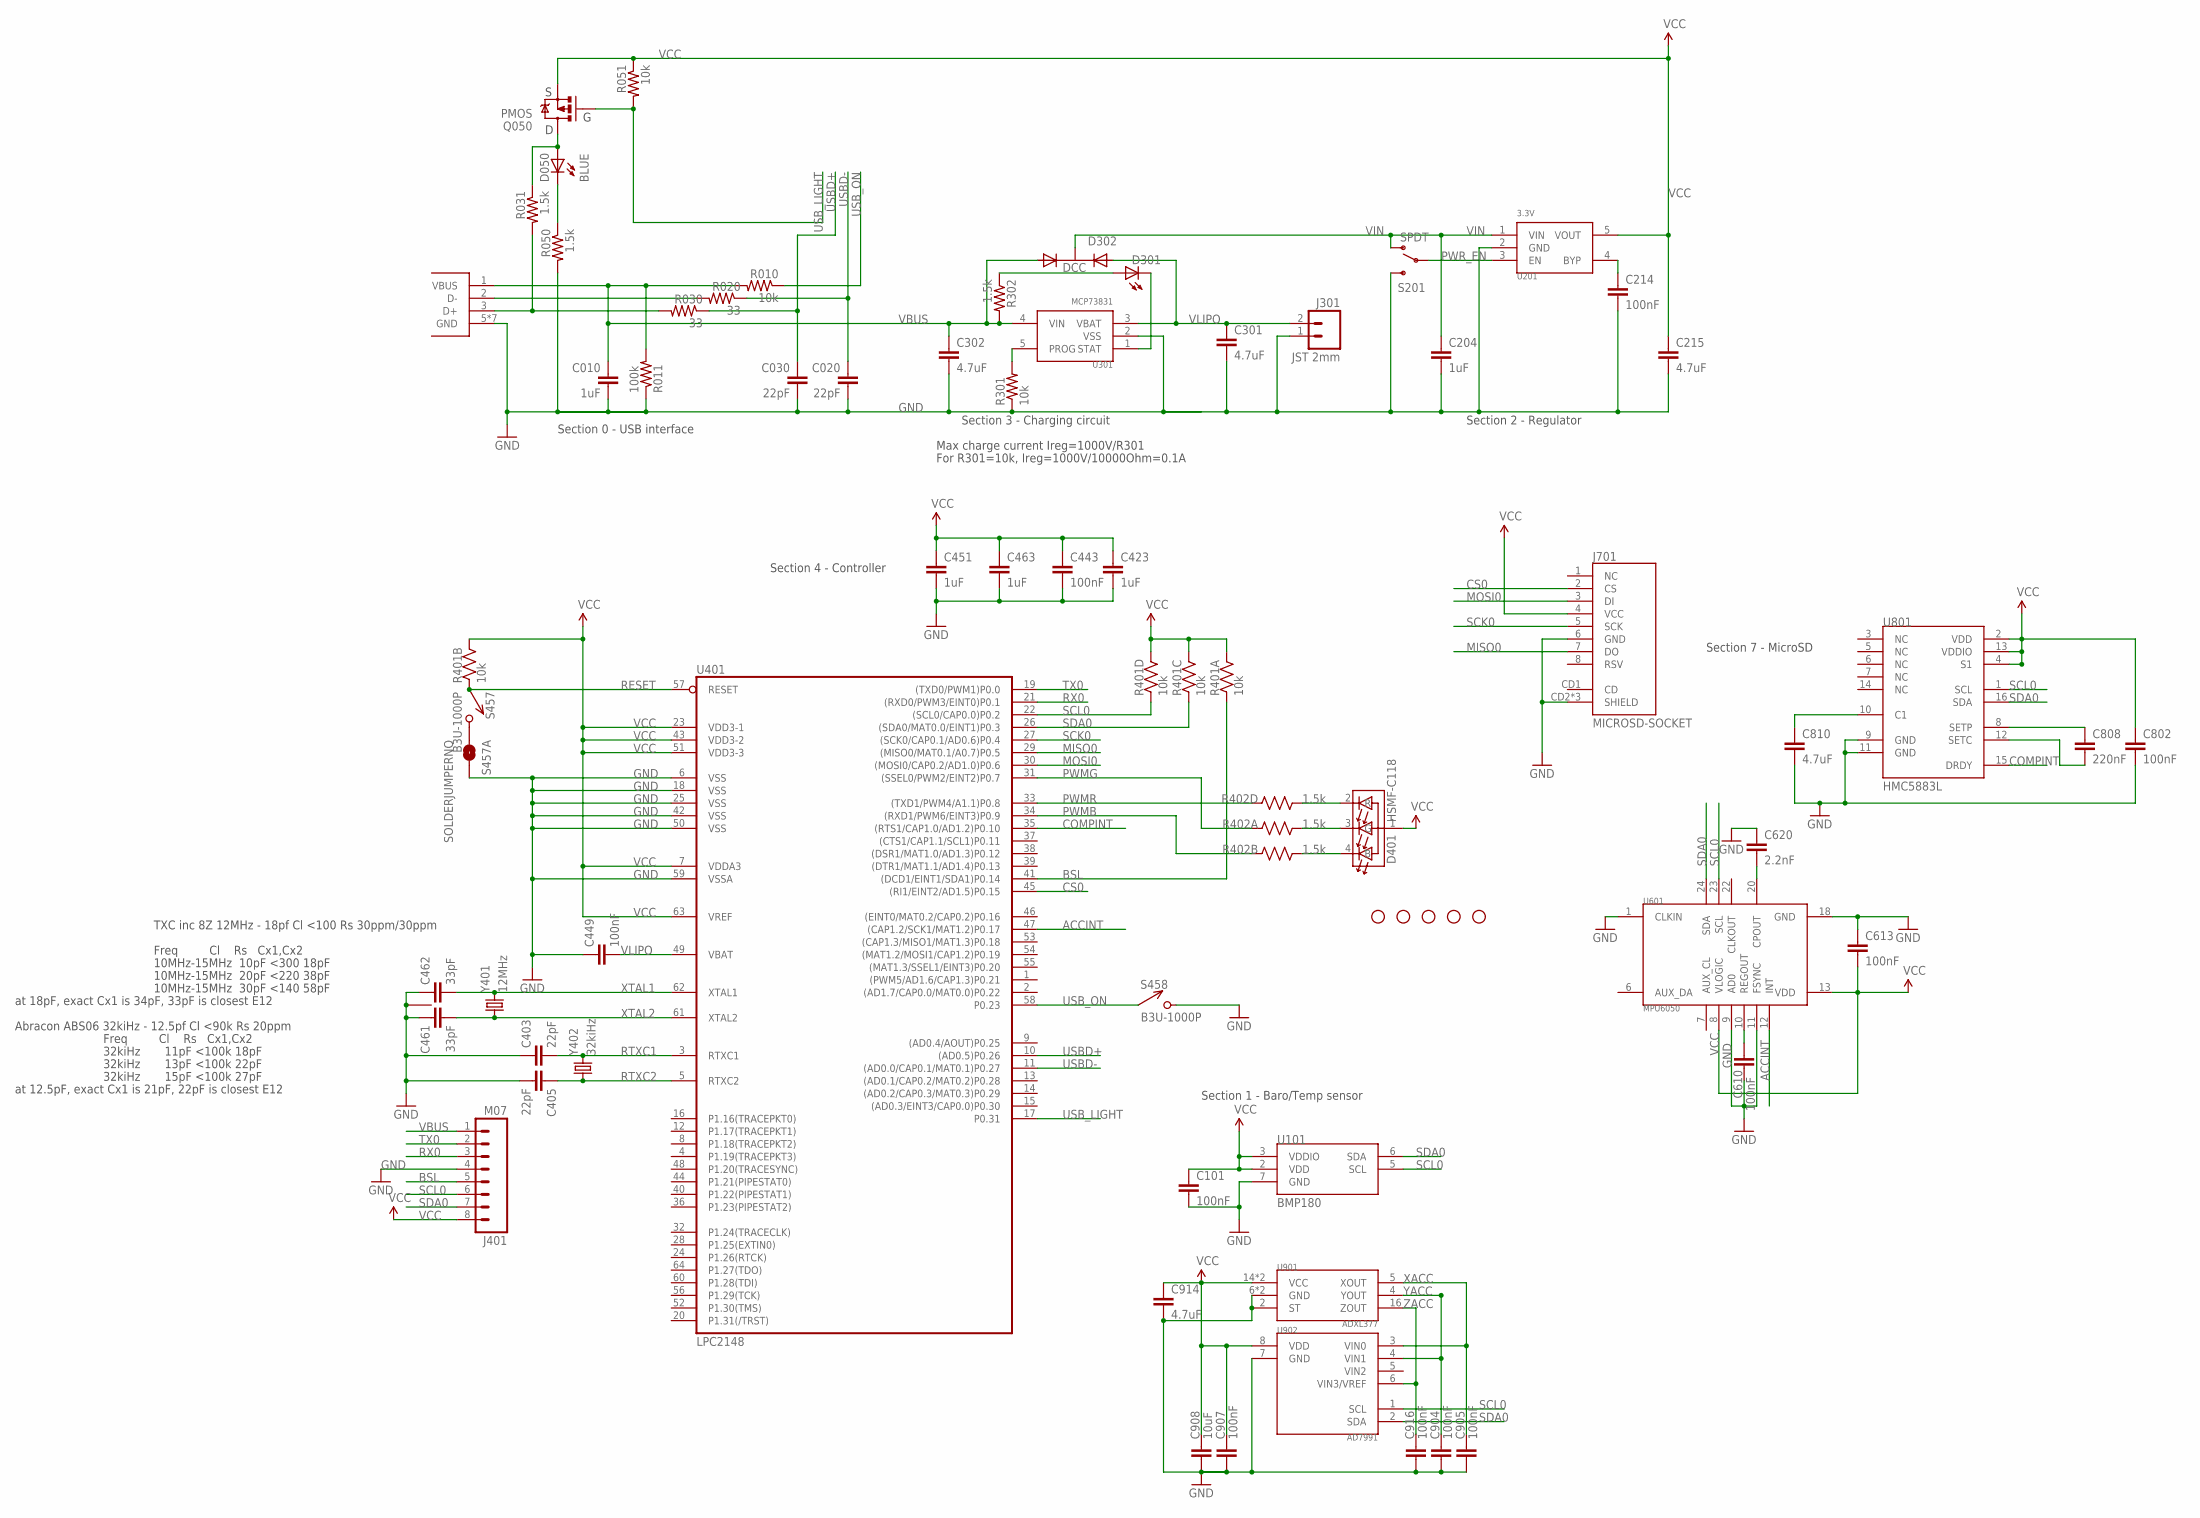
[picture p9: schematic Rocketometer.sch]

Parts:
C010, C204, C423, C451, C463: 1uF; 0402-CAP; DIGIKEY 445-4114-1-ND
C020, C030, C403, C405: 22pF; 0402-CAP; DIGIKEY 445-1239-1-ND
C101, C214, C443, C449, C610, C613, C802, C904, C905, C907, C916: 100nF; 0402-CAP; DIGIKEY 445-1265-1-ND
C215, C301, C302, C810, C914: 4.7uF; 0402-CAP; DIGIKEY 445-7395-1-ND
C461, C462: 33pF; 0402-CAP; DIGIKEY 445-1241-1-ND
C620: 2.2nF; 0402-CAP; DIGIKEY 445-1257-1-ND
C808: 220nF; 0402-CAP; DIGIKEY 445-5938-1-ND
C908: 10uF; 0603-CAP; DIGIKEY 445-7486-1-ND
D050: BLUE; LED-0603; DIGIKEY 350-2037-1-ND
D301: YELLOW; LED-0603; DIGIKEY 350-2032-1-ND
D302: DCC; SOT-23-3; DIGIKEY 568-6500-1-ND
D401: HSMF-C118; DIGIKEY 516-1778-1-ND
J001: USB_MICROB_JST; UB-MC5BR3-SD204-4S; DIGIKEY 455-2562-1-ND
J301: JST 2mm; JST-2-SMD; DIGIKEY 455-1749-1-ND
J401: M07; 1X08; DIGIKEY $NOPART
J701: MICROSD-SOCKET; MICROSD-SOCKET-PP; DIGIKEY 101-00581-59-1-ND
JP1, JP2, JP3, JP4, JP5: STAND-OFFTIGHT; STAND-OFF-TIGHT; DIGIKEY $NOPART
Q050: PMOS; SOT23-3; DIGIKEY NTR1P02T1GOSCT-ND
R010, R051, R301: 10k; 0402-RES; DIGIKEY P10.0KLCT-ND
R011: 100k; 0402-RES; DIGIKEY P100KLCT-ND
R020, R030: 33; 0402-RES; DIGIKEY P33.0LCT-ND
R031, R050, R302: 1.5k; 0402-RES; DIGIKEY P1.50KLCT-ND
R401: 10k; CRA04; DIGIKEY CRA4S810KCT-ND
R402: 1.5k; CRA04; DIGIKEY CRA4S81.5KCT-ND
S201: SPDT; AYZ0202; DIGIKEY 401-2013-1-ND
S457, S458: B3U-1000P; DIGIKEY SW1020CT-ND
S457A: SOLDERJUMPERNO; SJ_2S-NO; DIGIKEY $NOPART
U101: BMP180; DIGIKEY 828-1027-1-ND
U201: 3.3V; SOT-23-5; DIGIKEY 576-1910-1-ND
U301: MCP73831; SOT-23-5; DIGIKEY 576-1910-1-ND
U401: LPC2148; SQFP-S-10X10-64; DIGIKEY 568-1765-ND
U601: MPU6050; MPU60X0; DIGIKEY $NOPART
U801: HMC5883L; 16LPCC; DIGIKEY 342-1082-1-ND
U901: ADXL377; DIGIKEY ADXL377BCPZ-RL7CT-ND
U902: AD7991; SOT-23-8; DIGIKEY AD7991YRJZ-0500RL7CT-ND
Y401: 12MHz; CRYSTAL_SMD_2MM_2_5MM; DIGIKEY 887-1487-1-ND
Y402: 32kiHz; ABS06; DIGIKEY 535-10104-1-ND

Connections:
ACCINT: U401.47 ((CAP1.2/SCK1/MAT1.2)P0.17), U601.12 (INT)
BSL: J401.5, R401.1, U401.41 ((DCD1/EINT1/SDA1)P0.14)
COMPINT: U401.35 ((RTS1/CAP1.0/AD1.2)P0.10), U801.15 (DRDY)
CONN_D+: J001.3 (D+), R030.2, R031.2
CONN_D-: J001.2 (D-), R020.2
CS0: J701.2 (CS), U401.45 ((RI1/EINT2/AD1.5)P0.15)
GND: C010.2, C020.2, C030.2, C101.2, C204.2, C214.2, C215.2, C301.2, C302.2, C403.1, C405.2, C423.2, C443.2, C449.1, C451.2, C461.1, C462.1, C463.2, C610.2, C613.1, C620.1, C802.2, C810.2, C904.2, C905.2, C907.2, C908.2, C914.2, C916.2, J001.5 (GND), J001.P$6 (GND), J001.P$7 (GND), J001.P$8 (GND), J001.P$9 (GND), J001.P$10 (GND), J001.P$11 (GND), J301.1, J401.4, J701.6 (GND), J701.CD2 (SHIELD), J701.GND1 (SHIELD), J701.GND3 (SHIELD), R011.1, R050.2, R301.1, S201.3 (S), S457A.2, S458.P$2 (2), U101.7 (GND), U201.2 (GND), U301.2 (VSS), U401.6 (VSS), U401.18 (VSS), U401.25 (VSS), U401.42 (VSS), U401.50 (VSS), U401.59 (VSSA), U601.1 (CLKIN), U601.9 (AD0), U601.11 (FSYNC), U601.18 (GND), U801.9 (GND), U801.11 (GND), U901.2 (ST), U901.6 (GND), U901.7 (GND), U902.7 (GND), Y401.2 (1), Y401.4 (1)
MISO0: J701.7 (DO), U401.29 ((MISO0/MAT0.1/A0.7)P0.5)
MOSI0: J701.3 (DI), U401.30 ((MOSI0/CAP0.2/AD1.0)P0.6)
unnamed: C620.2, U601.20 (CPOUT)
unnamed: R301.2, U301.5 (PROG)
unnamed: D301.C, U301.1 (STAT)
unnamed: D301.A, R302.1
unnamed: D050.A, Q050.3 (D), R031.1
unnamed: D050.C, R050.1
unnamed: S457.P$2 (2), S457A.1
unnamed: C610.1, U601.10 (REGOUT)
unnamed: C808.1, U801.8 (SETP)
unnamed: C808.2, U801.12 (SETC)
unnamed: C810.1, U801.10 (C1)
unnamed: C214.1, U201.4 (BYP)
PWMB: R402.7 (2), U401.34 ((RXD1/PWM6/EINT3)P0.9)
PWMG: R402.8 (2), U401.31 ((SSEL0/PWM2/EINT2)P0.7)
PWMR: R402.5 (2), U401.33 ((TXD1/PWM4/A1.1)P0.8)
PWR_EN: S201.2, U201.3 (EN)
QWMB: D401.4 (B), R402.2 (1)
QWMG: D401.3 (G), R402.1
QWMR: D401.2 (R), R402.4 (1)
RESET: R401.2 (1), S457.P$1 (1), U401.57 (RESET)
RTXC1: C403.2, U401.3 (RTXC1), Y402.2
RTXC2: C405.1, U401.5 (RTXC2), Y402.1
RX0: J401.3, U401.21 ((RXD0/PWM3/EINT0)P0.1)
SCK0: J701.5 (SCK), U401.27 ((SCK0/CAP0.1/AD0.6)P0.4)
SCL0: J401.6, R401.4 (1), U101.5 (SCL), U401.22 ((SCL0/CAP0.0)P0.2), U601.23 (SCL), U801.1 (SCL), U902.1 (SCL)
SDA0: J401.7, R401.3 (1), U101.6 (SDA), U401.26 ((SDA0/MAT0.0/EINT1)P0.3), U601.24 (SDA), U801.16 (SDA), U902.2 (SDA)
TX0: J401.2, U401.19 ((TXD0/PWM1)P0.0)
USBD+: C030.1, R030.1, U401.10 ((AD0.5)P0.26)
USBD-: C020.1, R020.1, U401.11 ((AD0.0/CAP0.1/MAT0.1)P0.27)
USB_LIGHT: Q050.1 (G), R051.2, U401.17 (P0.31)
USB_ON: R010.1, S458.P$1 (1), U401.58 (P0.23)
VBUS: C010.1, C302.1, D302.1 (A1), J001.1 (VBUS), J401.1, R010.2, R011.2, R302.2, U301.4 (VIN)
VCC: C101.1, C215.1, C423.1, C443.1, C451.1, C463.1, C613.2, C802.1, C907.1, C908.1, C914.1, D401.1 (A), J401.8, J701.4 (VCC), Q050.2 (S), R051.1, R401.5 (2), R401.6 (2), R401.7 (2), R401.8 (2), U101.2 (VDD), U101.3 (VDDIO), U201.5 (VOUT), U401.7 (VDDA3), U401.23 (VDD3-1), U401.43 (VDD3-2), U401.51 (VDD3-3), U401.63 (VREF), U601.8 (VLOGIC), U601.13 (VDD), U801.2 (VDD), U801.4 (S1), U801.13 (VDDIO), U901.14 (VCC), U901.15 (VCC), U902.8 (VDD)
VIN: C204.1, D302.3 (K), S201.1 (O), U201.1 (VIN)
VLIPO: C301.1, C449.2, D302.2 (A2), J301.2, U301.3 (VBAT), U401.49 (VBAT)
XACC: C905.1, U901.5 (XOUT), U902.3 (VIN0)
XTAL1: C462.2, U401.62 (XTAL1), Y401.3 (2)
XTAL2: C461.2, U401.61 (XTAL2), Y401.1
YACC: C904.1, U901.4 (YOUT), U902.4 (VIN1)
ZACC: C916.1, U901.16 (ZOUT), U902.6 (VIN3/VREF)

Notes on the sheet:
Section 2 - Regulator
Section 3 - Charging circuit
Section 0 - USB interface
Section 4 - Controller
Section 7 - MicroSD
Section 1 - Baro/Temp sensor
Max charge current Ireg=1000V/R301
For R301=10k, Ireg=1000V/10000Ohm=0.1A
Freq Cl Rs Cx1,Cx2
10MHz-15MHz 10pF <300 18pF
10MHz-15MHz 20pF <220 38pF
10MHz-15MHz 30pF <140 58pF
TXC inc 8Z 12MHz - 18pf Cl <100 Rs 30ppm/30ppm
at 18pF, exact Cx1 is 34pF, 33pF is closest E12
32kiHz 11pF <100k 18pF
32kiHz 13pF <100k 22pF
32kiHz 15pF <100k 27pF
Abracon ABS06 32kiHz - 12.5pf Cl <90k Rs 20ppm
at 12.5pF, exact Cx1 is 21pF, 22pF is closest E12

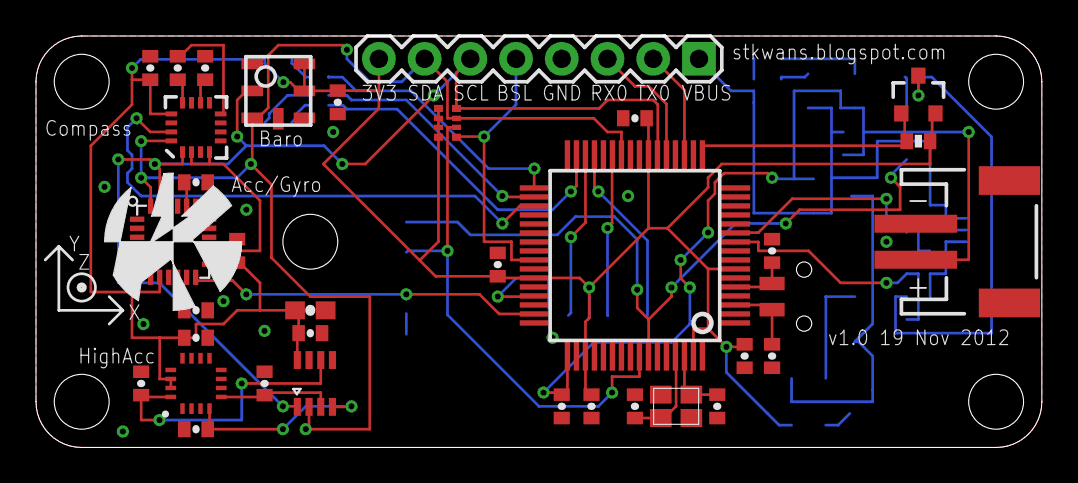
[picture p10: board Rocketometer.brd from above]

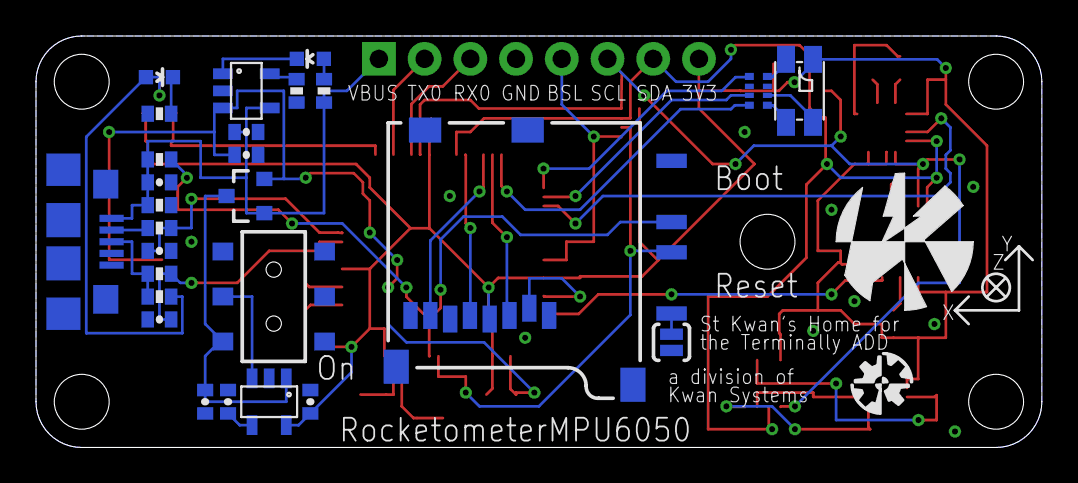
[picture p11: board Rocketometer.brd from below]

Board: 2 copper layers, 55.9 x 22.9 mm, 73 parts (31 on the bottom side), 49 nets.

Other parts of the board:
U$1, U$5: KWAN_ACC
U$4: AXES
U$6: OSHW_ACC

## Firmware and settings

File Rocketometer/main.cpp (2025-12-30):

#include <string.h>
#include "gpio.h"
#include "StateTwoWire.h"
#include "HardSPI.h"
#include "Serial.h"
#include "bmp180.h"
#include "hmc5883.h"
#include "mpu60x0.h"
#include "ad799x.h"
#include "Time.h"
#include "DirectTask.h"
#include "LPC214x.h"
#include "dump.h"
#include "packet.h"
#include "sdhc.h"
#include "Partition.h"
#include "cluster.h"
#include "direntry.h"
#include "file.h"
static const int blockSize=SDHC::BLOCK_SIZE;
#include "FileCircular.h"

//Once the log becomes greater or equal to this length, cycle the log file
//This way we don't violate the FAT file size limit, and don't choke our processing
//program with data.
//Set to 128MiB so that we can test the feature
const unsigned int maxLogSize=1024U*1024U*1024U;
const uint16_t resetFileSkip=10;

//int temperature, pressure;
//int temperatureRaw, pressureRaw;
char vbus;
volatile bool writeDrain=false;
volatile bool writeSd=false;
volatile unsigned int drainTC0,drainTC1;

const uint32_t fastReadPeriodMs=3;
const uint32_t slowReadPeriodMs=10*fastReadPeriodMs;
uint32_t readPeriodMs=fastReadPeriodMs; //Read period in ms

inline uint32_t abs(int in) {
  return in>0?in:-in;
}

StateTwoWire Wire1(0);
SDHC sd(&SPI,15);
SDHC_info sdinfo;
Partition p(sd);
Cluster fs(p);
File f(fs);
Hd sector(Serial);
BMP180 bmp180(Wire1);
HMC5883 hmc5883(Wire1);
MPU6050 mpu6050(Wire1,0);
AD799x ad799x(Wire1);
const int dumpPktSize=120;
Base85 d(Serial,dumpPktSize);
FileCircular pktStore(f);
CCSDS ccsds(pktStore);
unsigned short pktseq[32];

const char syncMark[]="KwanSync";

static uint16_t log_i=0;

void openLog(uint16_t inc=1) {
  Serial.println(inc,DEC);
  Serial.println(log_i,DEC);
  if(inc==0) blinklock(108);
  static char fn[13];
  if(fn[0]!='r') strcpy(fn,"rkto0000.sds");
  Serial.println(fn);
  while(log_i<9999 && f.find(fn)) {
    log_i+=inc;
    fn[4]='0'+log_i/1000;
    fn[5]='0'+(log_i%1000)/100;
    fn[6]='0'+(log_i%100)/10;
    fn[7]='0'+(log_i%10);
    Serial.println(fn);
  }
  bool worked=f.openw(fn);
  Serial.print("f.openw(\"");Serial.print(fn);Serial.print("\"): ");Serial.print(worked?"Worked":"didn't work");Serial.print(". Status code ");Serial.println(f.errno);
  if(!worked) blinklock(f.errno);
}

void closeLog() {
  f.close(); //Sync the directory entry - after this, we may reuse this file
               //object on a new file.
}

static const char version_string[]="Rocketometer v1.1 using Kwan FAT/SD library " __DATE__ " " __TIME__;

int16_t max,may,maz; //MPU60x0 acc
int16_t mgx,mgy,mgz; //MPU60x0 gyro
int16_t mt;          //MPU60x0 temp
int16_t bx,by,bz;    //compass (bfld)
uint16_t hx[4];      //HighAcc
bool wantPrint;
uint32_t TC,TC1;
int temperatureRaw,pressureRaw;
int16_t temperature;
int32_t pressure;

static void writeSdPacket() {
  ccsds.start(0x11);
  while(sd.buf.readylen()>0) ccsds.fill(sd.buf.get());
  ccsds.finish(0x11);
}

static void maybeWriteSdPacket() {
  if(sd.buf.readylen()>128) writeSdPacket();
}

bool isVertNow;
bool wasVert;
uint32_t vertTimeout;
uint32_t oldOvr;

void collectData(void* stuff) {
  //Don't bother to read the sensors if we can't store the data
  //this way we yield more time back to the writing routine so 
  //hopefully the buffer becomes empty sooner
  if(pktStore.isFull()) {
    directTaskManager.reschedule(1,readPeriodMs,0,collectData,0); 
    return; 
  }
  if(oldOvr!=pktStore.getBufOverflow()) {
    ccsds.start(0x15,pktseq,TC);
    ccsds.fill(pktStore.getBufOverflow());
    ccsds.finish(0x15);
    oldOvr=pktStore.getBufOverflow();
  }
  static int phase=0;
  static uint32_t bmpTC;
  static char old_vbus=0;
  phase++;
  TC=TTC(0);
  vbus=gpio_read(23);
  mpu6050.read(max,may,maz,mgx,mgy,mgz,mt);
  isVertNow=(abs(maz)>abs(max)) && (abs(maz)>abs(may));
  if(isVertNow) {
    vertTimeout=uptime()+20*60;
    if(!wasVert) {
      ccsds.start(0x14,pktseq,TC);
      ccsds.fill((char)1);
      ccsds.fill32((unsigned int)uptime());
      ccsds.fill32((unsigned int)vertTimeout);
      ccsds.finish(0x14);
    }
    wasVert=true;
  } else if (wasVert) {
    wasVert=vertTimeout>uptime();
    if(!wasVert) {
      ccsds.start(0x14,pktseq,TC);
      ccsds.fill((char)0);
      ccsds.fill32((unsigned int)uptime());
      ccsds.fill32((unsigned int)vertTimeout);
      ccsds.finish(0x14);
    }
  }
  readPeriodMs=wasVert?fastReadPeriodMs:slowReadPeriodMs;
  ad799x.read(hx);
  TC1=TTC(0);
  ccsds.start(0x10,pktseq,TC);
  ccsds.fill16(max);ccsds.fill16(may); ccsds.fill16(maz); ccsds.fill16(mgx); ccsds.fill16(mgy); ccsds.fill16(mgz); ccsds.fill16(mt);
  ccsds.fill((char*)hx,8);
  ccsds.fill32(TC1);
  ccsds.finish(0x10);
  if(vbus!=old_vbus) {
    ccsds.start(0x13,pktseq,TC);
    ccsds.fill(old_vbus);
    ccsds.fill(vbus);
    ccsds.finish(0x13);
    old_vbus=vbus;
  }
  if(0==(phase%20)) {
    //Only read the compass once every n times we read the 6DoF
    TC=TTC(0);
    hmc5883.read(bx,by,bz);
    ccsds.start(0x04,pktseq,TC);
    ccsds.fill16(bx);  ccsds.fill16(by);  ccsds.fill16(bz);
    ccsds.finish(0x04);
  }
  if((500/readPeriodMs)==phase) {
    //Only read the pressure sensor once every n times we read the 6DoF
    bmpTC=TTC(0);  
    bmp180.startMeasurement();
  } else if(bmp180.ready) {
    temperatureRaw=bmp180.getTemperatureRaw();
    pressureRaw=bmp180.getPressureRaw();
    temperature=bmp180.getTemperature();
    pressure=bmp180.getPressure();
    bmp180.ready=false;
    TC1=TTC(0);
    ccsds.start(0x0A,pktseq,bmpTC);
    ccsds.fill16(temperatureRaw);
    ccsds.fill32(pressureRaw);
    ccsds.fill16(temperature);
    ccsds.fill32(pressure);
    ccsds.fill32(TC1);
    ccsds.finish(0x0A);
    wantPrint=true;
    phase=0;
  }
  //Why here? Because since creation of packets is interrupt driven, and there
  //is only a single buffer, only the interrupt routine is allowed to write
  if(writeDrain) {
    ccsds.start(0x08,pktseq,drainTC0);
    ccsds.fill32(drainTC1);
    ccsds.finish(0x08);
    writeDrain=false;
  }
  if(writeSd) {
    writeSdPacket();
    writeSd=false;
  }
  directTaskManager.reschedule(1,readPeriodMs,0,collectData,0); 
}

void setup() {
  set_light(1,1);
  Serial.begin(230400);
  Serial.println(version_string);
  Wire1.begin();

  bool worked;
  worked=sd.begin();

  Serial.print("sd");    Serial.print(".begin ");Serial.print(worked?"Worked":"didn't work");Serial.print(". Status code ");Serial.println(sd.errno);
  if(!worked) blinklock(sd.errno);

  sd.get_info(sdinfo);
  sdinfo.print(Serial);
  worked=p.begin(1);
  Serial.print("p");     Serial.print(".begin ");Serial.print(worked?"Worked":"didn't work");Serial.print(". Status code ");Serial.println(p.errno);
  p.print(Serial);
  if(!worked) blinklock(p.errno);

  worked=fs.begin();  
  Serial.print("fs");    Serial.print(".begin ");Serial.print(worked?"Worked":"didn't work");Serial.print(". Status code ");Serial.println(fs.errno);
//  sector.begin();
  fs.print(Serial);//,sector);
  if(!worked) blinklock(fs.errno);


  openLog(resetFileSkip);
  pktStore.fill(syncMark);
  pktStore.mark();
  //Dump code to serial port and packet file
  int len=source_end-source_start;
  char* base=source_start;
  d.begin();
  while(len>0) {
    d.line(base,0,len>dumpPktSize?dumpPktSize:len);
    ccsds.start(0x03,pktseq);
    ccsds.fill16(base-source_start);
    ccsds.fill(base,len>dumpPktSize?dumpPktSize:len);
    ccsds.finish(0x03);
    pktStore.drain(); 
    maybeWriteSdPacket();
    base+=dumpPktSize;
    len-=dumpPktSize;
  }
  d.end();

  ccsds.start(0x12,pktseq);
  sdinfo.fill(ccsds);
  ccsds.finish(0x12);
  pktStore.drain(); 
  maybeWriteSdPacket();

  mpu6050.begin(3,3);
  Serial.print("MPU6050 identifier (should be 0x68): 0x");
  Serial.println(mpu6050.whoami(),HEX);
  ccsds.start(0x0F);
  mpu6050.fillConfig(ccsds);
  ccsds.finish(0x0F);
  pktStore.drain(); 
  maybeWriteSdPacket();

  hmc5883.begin();
  char HMCid[4];
  hmc5883.whoami(HMCid);
  Serial.print("HMC5883L identifier (should be 'H43'): ");
  Serial.println(HMCid);
  ccsds.start(0x0E);
  hmc5883.fillConfig(ccsds);
  ccsds.finish(0x0E);
  pktStore.drain(); 
  maybeWriteSdPacket();

  char channels=0x0B;
  worked=ad799x.begin(channels); 
  Serial.print("ad799x");Serial.print(".begin ");Serial.print(worked?"Worked":"didn't work");Serial.print(". Status code ");Serial.println(0);
  if(!worked) blinklock(0xAAAA5555);
  ccsds.start(0x0D);
  ccsds.fill(ad799x.getAddress());
  ccsds.fill(channels);
  ccsds.fill(ad799x.getnChannels());
  ccsds.fill((uint8_t)worked);
  ccsds.finish(0x0D);
  pktStore.drain(); 
  maybeWriteSdPacket();

  worked=bmp180.begin(2);
  Serial.print("bmp180");Serial.print(".begin ");Serial.print(worked?"Worked":"didn't work");Serial.print(". Status code ");Serial.println(0);
  Serial.print("BMP180 identifier (should be 0x55): 0x");
  Serial.println(bmp180.whoami(),HEX);
  if(!worked) blinklock(0x5555AAAA);
  bmp180.printCalibration(&Serial);

  bmp180.ouf=0;
  ccsds.start(0x02);

  bmp180.fillCalibration(ccsds);

  ccsds.finish(0x02);
  pktStore.drain(); 
  maybeWriteSdPacket();

  ccsds.start(0x0C);
  ccsds.fill32(HW_TYPE);
  ccsds.fill32(HW_SERIAL);
  ccsds.fill(MAMCR);
  ccsds.fill(MAMTIM);
  ccsds.fill16(PLL0STAT);
  ccsds.fill(VPBDIV);
  ccsds.fill32(FOSC);                   //Crystal frequency, Hz
  ccsds.fill32(CCLK);                   //Core Clock rate, Hz
  ccsds.fill32(PCLK);                   //Peripheral Clock rate, Hz
  ccsds.fill32(PREINT);  
  ccsds.fill32(PREFRAC);                    
  ccsds.fill(CCR);
  ccsds.fill(version_string);
  ccsds.finish(0x0C);
  pktStore.drain(); 
  maybeWriteSdPacket();

  //Set USB_ON to GPIO read
  set_pin(23,0,0);
  Serial.println("t,tc,bx,by,bz,max,may,maz,mgx,mgy,mgz,mt,h0,h1,h2,h3,T,P,vbus,ovr,wasVert,isVert");
//  Serial.println("t,tc,Traw,Praw");

  directTaskManager.begin();
  directTaskManager.schedule(1,readPeriodMs,0,collectData,0); 
}

void loop() {
  drainTC0=TTC(0);  
  if(pktStore.drain()) {
    flicker();
    writeDrain=true;
    drainTC1=TTC(0);
    if(sd.buf.readylen()>128) writeSd=true;
    uint32_t logSize;
    logSize=f.size();
    if(logSize>=maxLogSize) {
      closeLog();
      openLog();
      pktStore.fill(syncMark);
      pktStore.mark();
    }
  }
  if(pktStore.errno!=0) {
    Serial.print("Problem writing file: pktStore.errno=");
    Serial.println(pktStore.errno);
    blinklock(pktStore.errno);
  }
  if(wantPrint) {
    Serial.print(RTCHOUR,DEC,2);
    Serial.print(":");Serial.print(RTCMIN,DEC,2);
    Serial.print(":");Serial.print(((unsigned int)(TC/PCLK)),DEC,2);
    Serial.print(".");Serial.print(((unsigned int)((TC%PCLK)/(PCLK/1000))),DEC,3);
    Serial.print(",");Serial.print(((unsigned int)(TC)),DEC,10);
    Serial.print(",");Serial.print(bx, DEC); 
    Serial.print(",");Serial.print(by, DEC); 
    Serial.print(",");Serial.print(bz, DEC); 
    Serial.print(",");Serial.print(max, DEC);
    Serial.print(",");Serial.print(may, DEC);
    Serial.print(",");Serial.print(maz, DEC);
    Serial.print(",");Serial.print(mgx, DEC);
    Serial.print(",");Serial.print(mgy, DEC);
    Serial.print(",");Serial.print(mgz, DEC);
    Serial.print(",");Serial.print(mt, DEC);
    Serial.print(",");Serial.print(hx[0], HEX,4); 
    Serial.print(",");Serial.print(hx[1], HEX,4); 
    Serial.print(",");Serial.print(hx[2], HEX,4); 
    Serial.print(",");Serial.print(hx[3], HEX,4); 
    Serial.print(",");Serial.print(temperature/10, DEC);    
    Serial.print(".");Serial.print(temperature%10, DEC);    
    Serial.print(",");Serial.print((unsigned int)pressure, DEC); 
    Serial.print(",");Serial.print(vbus, DEC); 
    Serial.print(",");Serial.print((unsigned int)pktStore.getBufOverflow(), DEC); 
    Serial.print(",");Serial.print(wasVert?1:0, DEC); 
    Serial.print(",");Serial.print(isVertNow?1:0, DEC); 
    Serial.println();
    wantPrint=false;
  }
}

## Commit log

2025-12-30 Initial commit, exactly as downlinked in firmware.tar.gz as extracted from RKTO0620.SDS
    [Rocketometer.brd, Rocketometer.sch]
2025-12-30 Add extract and import scripts
    [apid list.ods]
2026-01-02 Add kicad import of Rocketometer as extracted from Eagle files from RKTO0620.SDS
    [AYZ0202AGRLC.STEP, HSMF-C118.STEP, QFN24_4X4X0P9-0P5_TDK.step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]

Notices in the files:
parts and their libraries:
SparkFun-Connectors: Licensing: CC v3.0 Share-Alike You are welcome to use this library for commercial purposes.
